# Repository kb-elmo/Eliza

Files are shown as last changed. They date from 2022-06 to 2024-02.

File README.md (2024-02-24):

# Eliza

[][cc-by-nc-sa]<a href="https://ko-fi.com/kb_elmo">kofibadge</a>

### A seamless, gasketmounted 12u 40% alice-style ergo keyboard

<!--<img src="https://i.imgur.com/x00N9f3.jpg" alt="header" width="800"/>-->

### This board is still in the testing prototype phase. 
#### Use the files at your own risk.

---

[STEP files for the case](case/)

[KiCAD PCB files](pcb/)

[Gerbers for PCB production](pcb/gerbers/)

[JLCPCB BOM](pcb/fab/Eliza_bom_jlc.csv)

[JLCPCB CPL](pcb/fab/Eliza_cpl_jlc.csv)

[Vial-QMK firmware](firmware/)

---

This work is licensed under a
[Creative Commons Attribution-NonCommercial-ShareAlike 4.0 International License][cc-by-nc-sa].

[][cc-by-nc-sa]

[cc-by-nc-sa]: http://creativecommons.org/licenses/by-nc-sa/4.0/
[cc-by-nc-sa-image]: https://licensebuttons.net/l/by-nc-sa/4.0/88x31.png
[cc-by-nc-sa-shield]: https://img.shields.io/badge/License-CC%20BY--NC--SA%204.0-lightgrey.svg

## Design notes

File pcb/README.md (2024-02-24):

# Eliza PCB

### Features

- Powered by an Atmega32u2
- Basic ESD and overvoltage protection
- Centered USB type-C port for a detachable cable
- Fully programmable using [QMK](https://qmk.fm) and [Vial](https://get.vial.today)

---

### Supported layouts

layout

---

### Preview

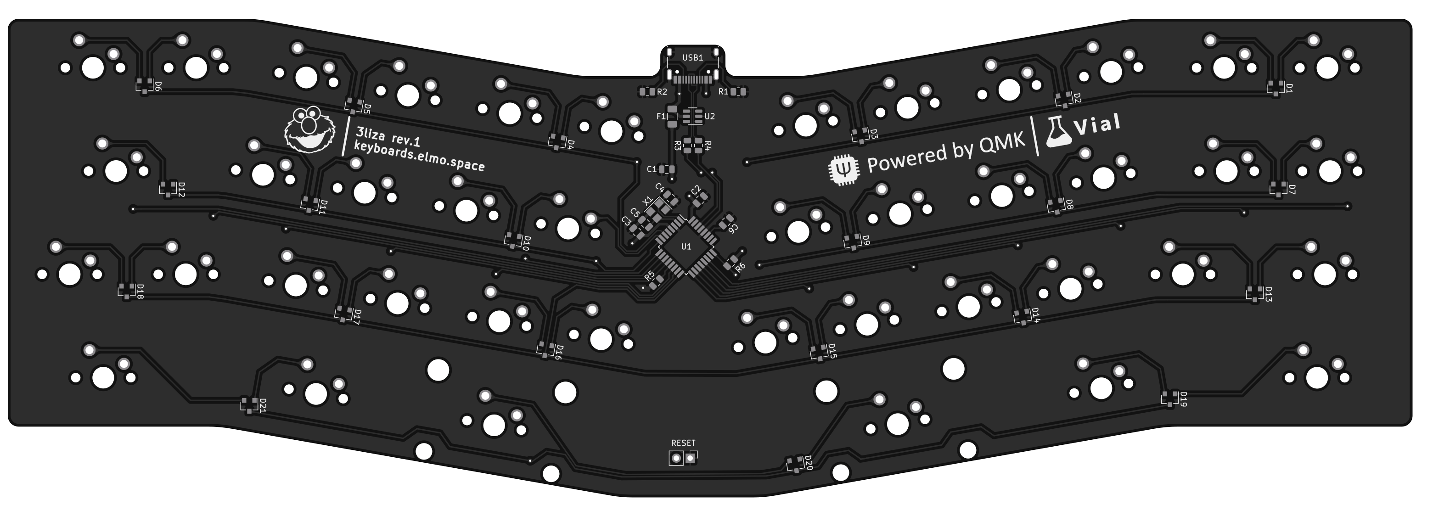
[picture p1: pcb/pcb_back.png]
pcb_back

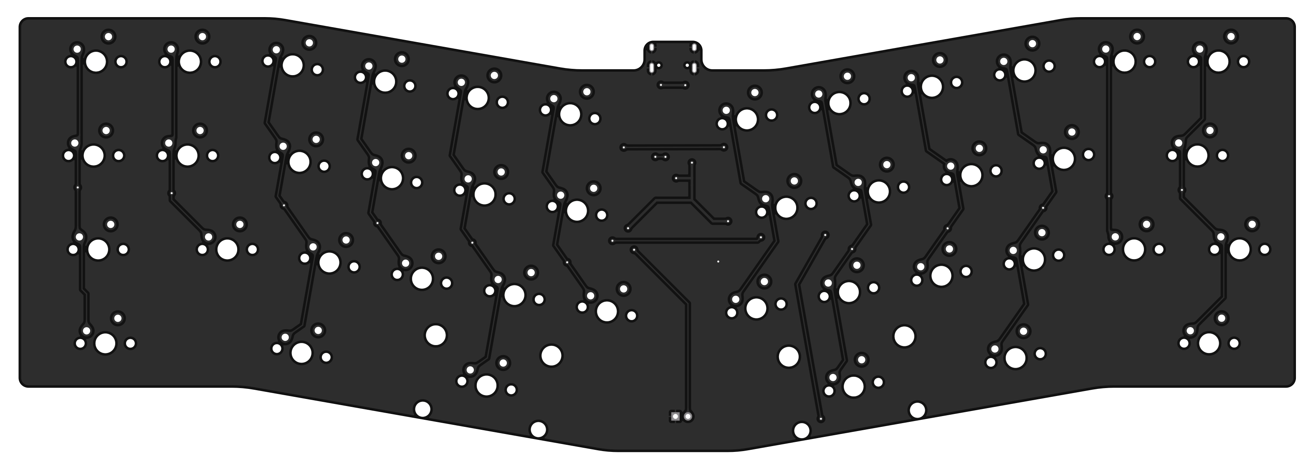
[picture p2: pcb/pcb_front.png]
pcb_front


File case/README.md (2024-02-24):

# Eliza case

### These files are meant for 3D printing only! 

They are not suitable for CNC machining and trying to use them for that will most likely result in failure of the parts.  
The plate is split in to two pieces for easier printing on smaller printers.

To assemble the board you need 6x m2x4mm heat set inserts and 6x m2x6mm screws.  
For mounting the plate in the case 16x 2mm thick foam strips should be used as gaskets.

---

### Supported layouts

layout

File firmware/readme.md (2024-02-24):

# Eliza

Eliza

40% alice-style ergo keyboard with a 3D printed case.

* Keyboard Maintainer: [kb-elmo](https://github.com/kb-elmo)
* Hardware Supported: Eliza rev.1 PCB
* Hardware Availability: [Open source project](https://github.com/kb-elmo/eliza)

Make example for this keyboard (after setting up your build environment):

    make kb_elmo/eliza:default

Flashing example for this keyboard:

    make kb_elmo/eliza:default:flash

See the [build environment setup](https://docs.qmk.fm/#/getting_started_build_tools) and the [make instructions](https://docs.qmk.fm/#/getting_started_make_guide) for more information. Brand new to QMK? Start with our [Complete Newbs Guide](https://docs.qmk.fm/#/newbs).

## Bootloader

Enter the bootloader in 3 ways:

* **Bootmagic reset**: Hold down the top left key and plug in the keyboard
* **Physical reset**: Briefly short the two contacts labeled "RESET" on the back of the PCB
* **Keycode in layout**: Press the key mapped to `RESET` if it is available

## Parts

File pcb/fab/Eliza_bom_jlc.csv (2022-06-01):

Comment | Designator | Footprint | LCSC Part #
10uF | C1 | C_0805_2012Metric | C91245
0.1uF | C2,C3 | C_0805_2012Metric | C49678
22pF | C4,C5 | C_0805_2012Metric | C1804
1uF | C6 | C_0805_2012Metric | C24123
D_Small | D1,D2,D3,D4,D5,D6,D7,D8,D9,D10,D11,D12,D13,D14,D15,D16,D17,D18,D19,D20,D21 | D_SOT-23_ANK_norm | C68978
Polyfuse_Small | F1 | Fuse_1206_3216Metric | C69688
5.1k | R1,R2 | R_0805_2012Metric | C27834
22 | R3,R4 | R_0805_2012Metric | C17561
10k | R5,R6 | R_0805_2012Metric | C17414
ATmega32U2-A | U1 | TQFP-32_7x7mm_P0.8mm | C618733
SRV05-4 | U2 | SOT-23-6 | C85364
USB_C_Receptacle_USB2.0 | USB1 | USB_C_Receptacle_HRO_TYPE-C-31-M-12 | C165948
Crystal_GND24_Small | X1 | Crystal_SMD_3225-4Pin_3.2x2.5mm | C13738

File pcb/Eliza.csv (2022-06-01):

Comment | Designator | Footprint | LCSC
10uF | C1 | Capacitor_SMD:C_0805_2012Metric | C91245
0.1uF | C2,C3 | Capacitor_SMD:C_0805_2012Metric | C49678
22pF | C4,C5 | Capacitor_SMD:C_0805_2012Metric | C1804
1uF | C6 | Capacitor_SMD:C_0805_2012Metric | C24123
D_Small | D1,D2,D3,D4,D5,D6,D7,D8,D9,D10,D11,D12,D13,D14,D15,D16,D17,D18,D19,D20,D21 | custom_parts:D_SOT-23_ANK_norm | C68978
Polyfuse_Small | F1 | Fuse:Fuse_1206_3216Metric | C69688
MX-NoLED | MX1,MX2,MX3,MX4,MX5,MX6,MX7,MX8,MX9,MX10,MX11,MX12,MX13,MX14,MX15,MX16,MX17,MX18,MX19,MX20,MX21,MX22,MX23,MX24,MX25,MX26,MX27,MX28,MX29,MX30,MX31,MX32,MX33,MX34,MX35,MX36,MX37,MX40,MX41 | MX_Only:MXOnly-1U-NoLED
MX-NoLED | MX38 | MX_Only:MXOnly-2.75U-ReversedStabilizers-NoLED
MX-NoLED | MX39 | MX_Only:MXOnly-2.25U-ReversedStabilizers-NoLED
5.1k | R1,R2 | Resistor_SMD:R_0805_2012Metric | C27834
22 | R3,R4 | Resistor_SMD:R_0805_2012Metric | C17561
10k | R5,R6 | Resistor_SMD:R_0805_2012Metric | C17414
RESET | RESET1 | Connector_PinHeader_2.54mm:PinHeader_1x02_P2.54mm_Vertical
ATmega32U2-A | U1 | Package_QFP:TQFP-32_7x7mm_P0.8mm | C618733
SRV05-4 | U2 | Package_TO_SOT_SMD:SOT-23-6 | C85364
USB_C_Receptacle_USB2.0 | USB1 | Connector_USB:USB_C_Receptacle_HRO_TYPE-C-31-M-12 | C165948
Crystal_GND24_Small | X1 | Crystal:Crystal_SMD_3225-4Pin_3.2x2.5mm | C13738

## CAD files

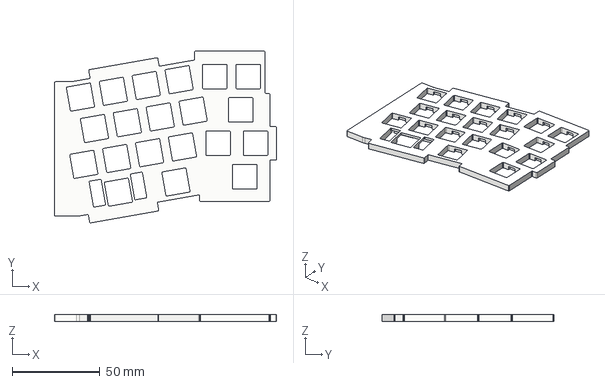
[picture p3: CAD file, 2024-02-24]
case/Eliza_plate_right.step
126.6 x 98.0 x 4.00 mm

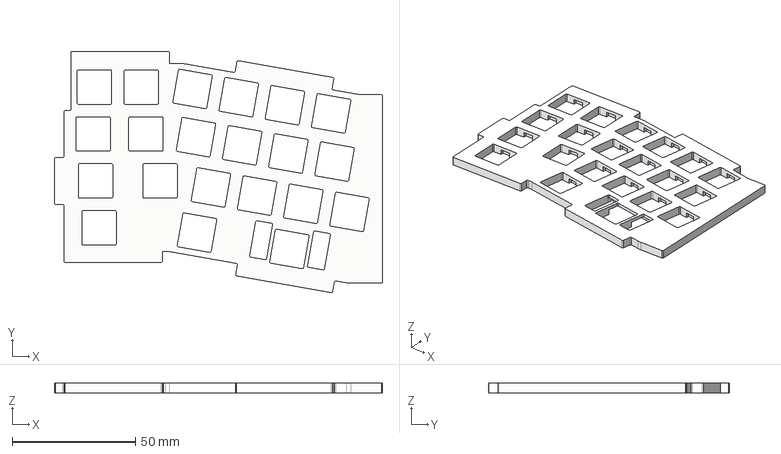
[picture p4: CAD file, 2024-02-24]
case/Eliza_plate_left.step
133.2 x 98.0 x 4.00 mm

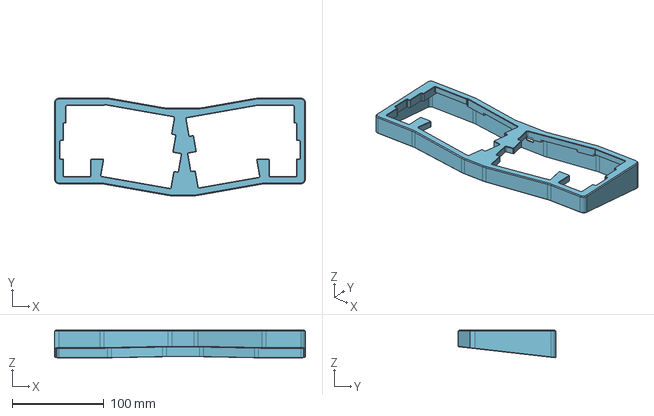
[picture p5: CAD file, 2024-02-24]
case/Eliza_top.step
273.0 x 106.3 x 30.1 mm

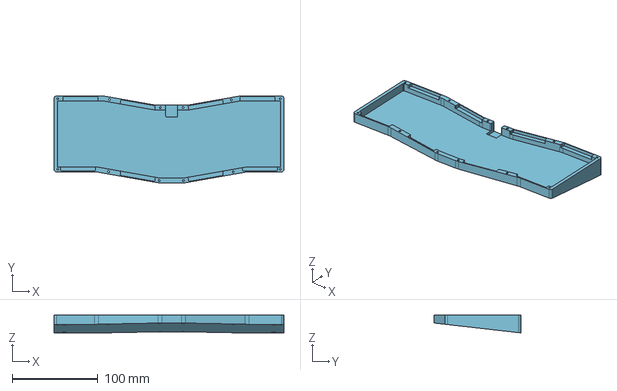
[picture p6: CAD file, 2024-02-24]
case/Eliza_bottom.step
268.6 x 101.9 x 20.9 mm

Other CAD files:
case/3liza_plate_right.step
case/3liza_top.step
case/3liza_plate_left.step
case/3liza_bottom.step

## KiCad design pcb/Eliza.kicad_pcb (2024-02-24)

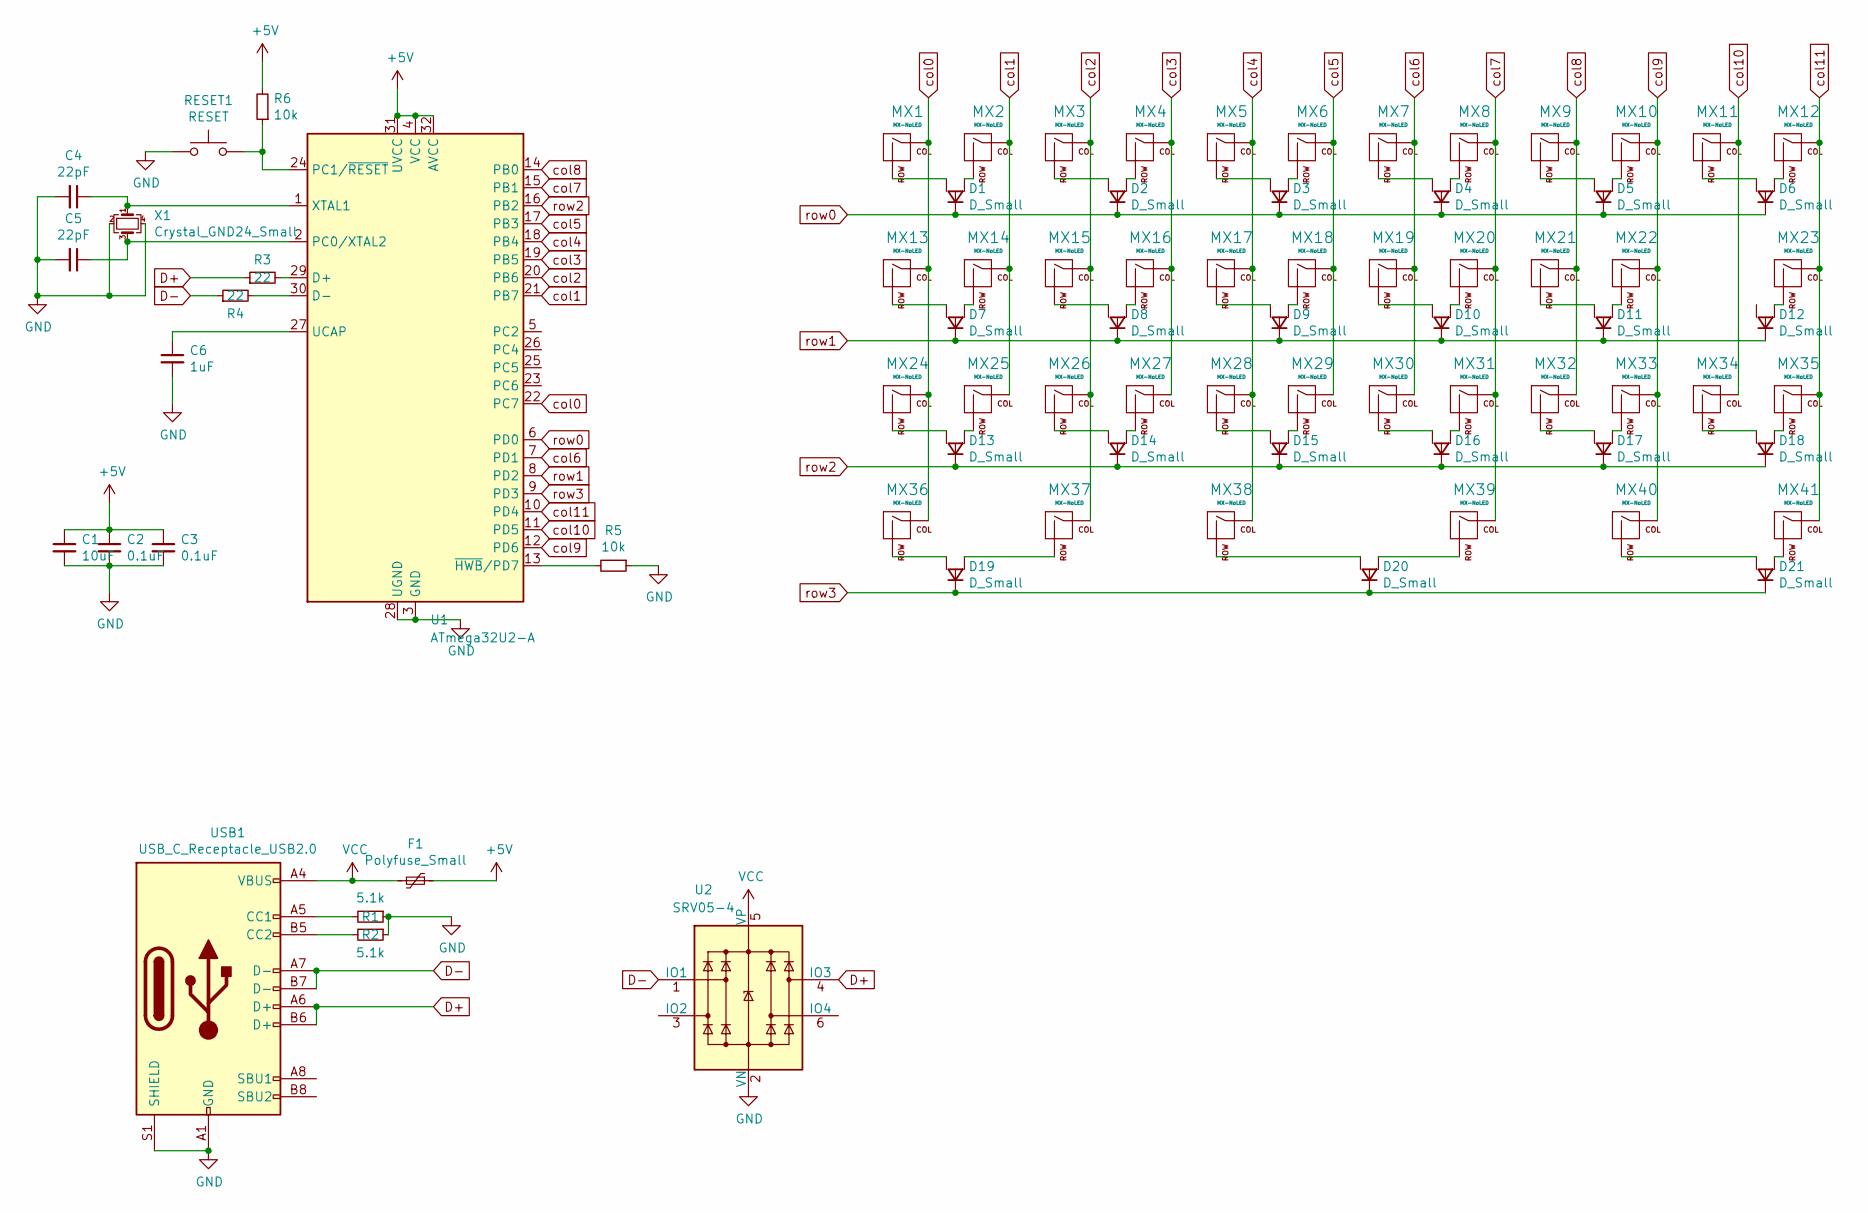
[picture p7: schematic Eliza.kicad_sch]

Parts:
C1: 10uF; C_0805_2012Metric; LCSC C91245
C2, C3: 0.1uF; C_0805_2012Metric; LCSC C49678
C4, C5: 22pF; C_0805_2012Metric; LCSC C1804
C6: 1uF; C_0805_2012Metric; LCSC C24123
D1, D2, D3, D4, D5, D6, D7, D8, D9, D10, D11, D12, D13, D14, D15, D16, D17, D18, D19, D20, D21: D_Small; D_SOT-23_ANK_norm; LCSC C68978
F1: Polyfuse_Small; Fuse_1206_3216Metric; LCSC C69688
MX1, MX2, MX3, MX4, MX5, MX6, MX7, MX8, MX9, MX10, MX11, MX12, MX13, MX14, MX15, MX16, MX17, MX18, MX19, MX20, MX21, MX22, MX23, MX24, MX25, MX26, MX27, MX28, MX29, MX30, MX31, MX32, MX33, MX34, MX35, MX36, MX37, MX40, MX41: MX-NoLED; MXOnly-1U-NoLED
MX38: MX-NoLED; MXOnly-2.75U-ReversedStabilizers-NoLED
MX39: MX-NoLED; MXOnly-2.25U-ReversedStabilizers-NoLED
R1, R2: 5.1k; R_0805_2012Metric; LCSC C27834
R3, R4: 22; R_0805_2012Metric; LCSC C17561
R5, R6: 10k; R_0805_2012Metric; LCSC C17414
RESET1: RESET; PinHeader_1x02_P2.54mm_Vertical
U1: ATmega32U2-A; TQFP-32_7x7mm_P0.8mm; LCSC C618733
U2: SRV05-4; SOT-23-6; LCSC C85364
USB1: USB_C_Receptacle_USB2.0; USB_C_Receptacle_HRO_TYPE-C-31-M-12; LCSC C165948
X1: Crystal_GND24_Small; Crystal_SMD_3225-4Pin_3.2x2.5mm; LCSC C13738

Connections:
+5V: C1.1, C2.1, C3.1, F1.1, R6.2, U1.4 (VCC), U1.31 (UVCC), U1.32 (AVCC)
D+: R3.1, U2.4 (IO3), USB1.A6 (D+), USB1.B6 (D+)
D-: R4.1, U2.1 (IO1), USB1.A7 (D-), USB1.B7 (D-)
GND: C1.2, C2.2, C3.2, C4.2, C5.2, C6.2, R1.1, R2.1, R5.1, RESET1.1, U1.3 (GND), U1.28 (UGND), U2.2 (VN), USB1.A1 (GND), USB1.A12 (GND), USB1.B1 (GND), USB1.B12 (GND), USB1.S1 (SHIELD), X1.2, X1.4; also elsewhere on the board
unnamed: C4.1, U1.1 (XTAL1), X1.1
unnamed: C5.1, U1.2 (PC0/XTAL2), X1.3
unnamed: C6.1, U1.27 (UCAP)
unnamed: D1.2 (A1), MX1.2 (ROW)
unnamed: D1.3 (A2), MX2.2 (ROW)
unnamed: D2.2 (A1), MX3.2 (ROW)
unnamed: D2.3 (A2), MX4.2 (ROW)
unnamed: D3.2 (A1), MX5.2 (ROW)
unnamed: D3.3 (A2), MX6.2 (ROW)
unnamed: D4.2 (A1), MX7.2 (ROW)
unnamed: D4.3 (A2), MX8.2 (ROW)
unnamed: D5.2 (A1), MX9.2 (ROW)
unnamed: D5.3 (A2), MX10.2 (ROW)
unnamed: D6.2 (A1), MX11.2 (ROW)
unnamed: D6.3 (A2), MX12.2 (ROW)
unnamed: D7.2 (A1), MX13.2 (ROW)
unnamed: D7.3 (A2), MX14.2 (ROW)
unnamed: D8.2 (A1), MX15.2 (ROW)
unnamed: D8.3 (A2), MX16.2 (ROW)
unnamed: D9.2 (A1), MX17.2 (ROW)
unnamed: D9.3 (A2), MX18.2 (ROW)
unnamed: D10.2 (A1), MX19.2 (ROW)
unnamed: D10.3 (A2), MX20.2 (ROW)
unnamed: D11.2 (A1), MX21.2 (ROW)
unnamed: D11.3 (A2), MX22.2 (ROW)
unnamed: D12.3 (A2), MX23.2 (ROW)
unnamed: D13.2 (A1), MX24.2 (ROW)
unnamed: D13.3 (A2), MX25.2 (ROW)
unnamed: D14.2 (A1), MX26.2 (ROW)
unnamed: D14.3 (A2), MX27.2 (ROW)
unnamed: D15.2 (A1), MX28.2 (ROW)
unnamed: D15.3 (A2), MX29.2 (ROW)
unnamed: D16.2 (A1), MX30.2 (ROW)
unnamed: D16.3 (A2), MX31.2 (ROW)
unnamed: D17.2 (A1), MX32.2 (ROW)
unnamed: D17.3 (A2), MX33.2 (ROW)
unnamed: D18.2 (A1), MX34.2 (ROW)
unnamed: D18.3 (A2), MX35.2 (ROW)
unnamed: D19.2 (A1), MX36.2 (ROW)
unnamed: D19.3 (A2), MX37.2 (ROW)
unnamed: D20.2 (A1), MX38.2 (ROW)
unnamed: D20.3 (A2), MX39.2 (ROW)
unnamed: D21.2 (A1), MX40.2 (ROW)
unnamed: D21.3 (A2), MX41.2 (ROW)
unnamed: R1.2, USB1.A5 (CC1)
unnamed: R2.2, USB1.B5 (CC2)
unnamed: R3.2, U1.29 (D+)
unnamed: R4.2, U1.30 (D-)
unnamed: R5.2, U1.13 (~HWB/PD7)
unnamed 53: R6.1, RESET1.2, U1.24 (PC1/~RESET); also elsewhere on the board
VCC: F1.2, U2.5 (VP), USB1.A4 (VBUS), USB1.A9 (VBUS), USB1.B4 (VBUS), USB1.B9 (VBUS)
col0: MX1.1 (COL), MX13.1 (COL), MX24.1 (COL), MX36.1 (COL), U1.22 (PC7)
col1: MX2.1 (COL), MX14.1 (COL), MX25.1 (COL), U1.21 (PB7)
col2: MX3.1 (COL), MX15.1 (COL), MX26.1 (COL), MX37.1 (COL), U1.20 (PB6)
col3: MX4.1 (COL), MX16.1 (COL), MX27.1 (COL), U1.19 (PB5)
col4: MX5.1 (COL), MX17.1 (COL), MX28.1 (COL), MX38.1 (COL), U1.18 (PB4)
col5: MX6.1 (COL), MX18.1 (COL), MX29.1 (COL), U1.17 (PB3)
col6: MX7.1 (COL), MX19.1 (COL), MX30.1 (COL), U1.7 (PD1)
col7: MX8.1 (COL), MX20.1 (COL), MX31.1 (COL), MX39.1 (COL), U1.15 (PB1)
col8: MX9.1 (COL), MX21.1 (COL), MX32.1 (COL), U1.14 (PB0)
col9: MX10.1 (COL), MX22.1 (COL), MX33.1 (COL), MX40.1 (COL), U1.12 (PD6)
col10: MX11.1 (COL), MX34.1 (COL), U1.11 (PD5)
col11: MX12.1 (COL), MX23.1 (COL), MX35.1 (COL), MX41.1 (COL), U1.10 (PD4)
row0: D1.1 (K), D2.1 (K), D3.1 (K), D4.1 (K), D5.1 (K), D6.1 (K), U1.6 (PD0)
row1: D7.1 (K), D8.1 (K), D9.1 (K), D10.1 (K), D11.1 (K), D12.1 (K), U1.8 (PD2)
row2: D13.1 (K), D14.1 (K), D15.1 (K), D16.1 (K), D17.1 (K), D18.1 (K), U1.16 (PB2)
row3: D19.1 (K), D20.1 (K), D21.1 (K), U1.9 (PD3)

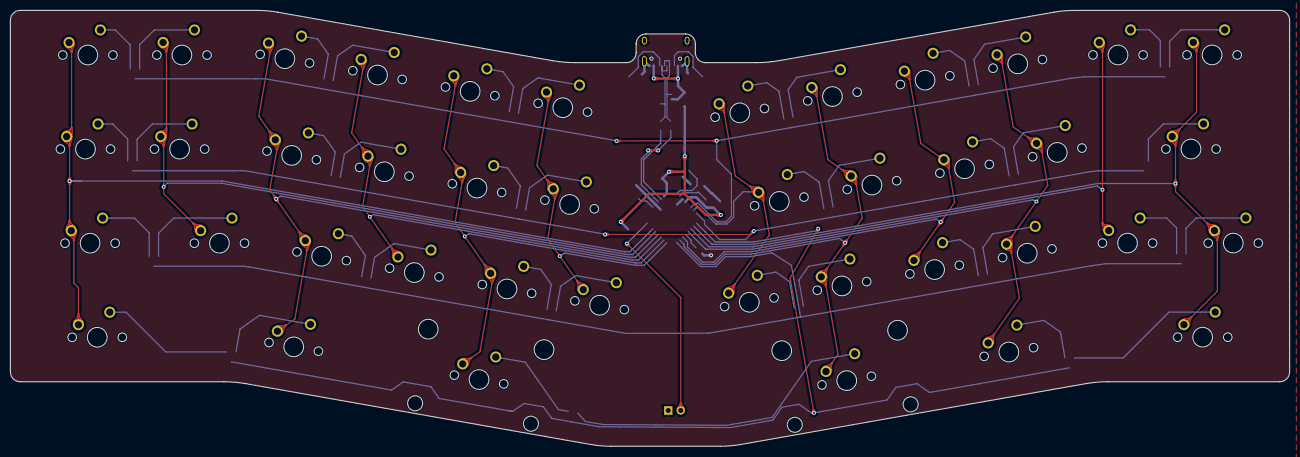
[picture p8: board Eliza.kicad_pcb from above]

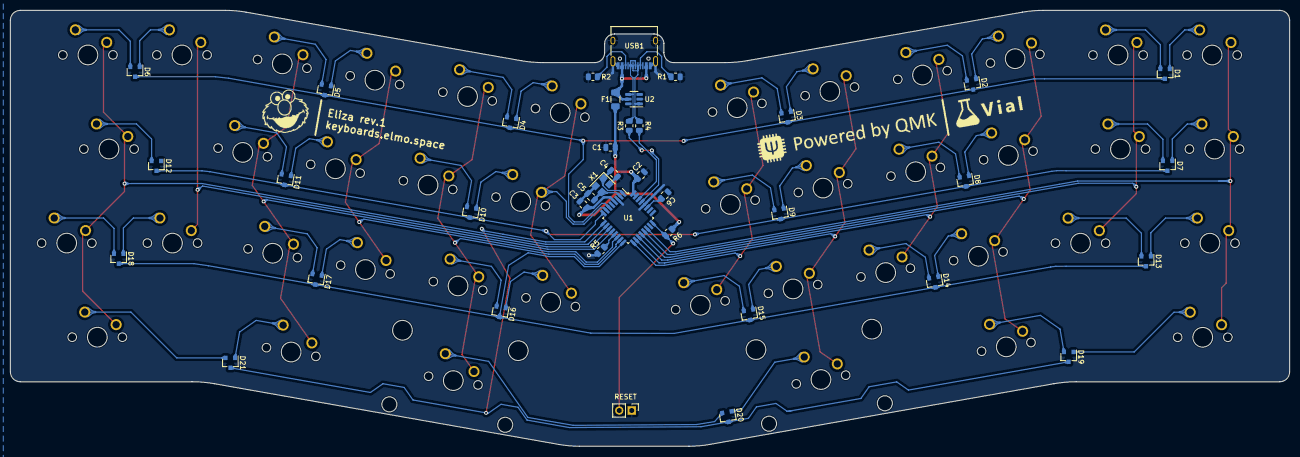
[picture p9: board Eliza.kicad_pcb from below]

Board: 2 copper layers, 259.0 x 88.3 mm, 80 parts (39 on the bottom side), 71 nets.

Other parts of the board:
RESET: RESET; PinHeader_1x02_P2.54mm_Vertical

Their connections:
GND: RESET.1; also elsewhere on the board
unnamed 53: RESET.2; also elsewhere on the board

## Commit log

2022-06-01 move files
    [3liza_bom_jlc.csv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]
2022-06-01 add case files
    [3liza_bottom.step, 3liza_plate_left.step, 3liza_plate_right.step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]
2024-02-21 fix pcb renders
    [3liza-CmtUser.gbr, 3liza-CuBottom.gbr, 3liza-CuTop.gbr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]
2024-02-21 remove pcb test files
    [3liza-CmtUser.gbr, 3liza-CuBottom.gbr, 3liza-CuTop.gbr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]
2024-02-24 Rename and small updates
    [3liza.kicad_pcb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]

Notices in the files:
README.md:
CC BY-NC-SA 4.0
